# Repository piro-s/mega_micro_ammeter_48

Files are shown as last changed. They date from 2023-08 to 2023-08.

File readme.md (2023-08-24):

## Mega micro ammeter 48  
The microammeter is designed to measure small direct currents in low-voltage 
circuits and has the following characteristics:  
+ range of measured currents: 0.05 μA - 500 mA in 6 ranges;  
+ automatic range selection;  
+ results on a display 1602;  
+ building a current graph on a PC (connect via micro USB);  
+ potential at the current measurement point: 0 - 6 V;  
+ power: 5V, via connector micro USB.  
iso_v0.2_top iso_v0.2__bottom  
Устройство построено на основе статьи

---
#### Scheme:  
[Scheme_v0.2](docs/mega_micro_ammeter_48_v0.2.pdf)  

#### PCB:  
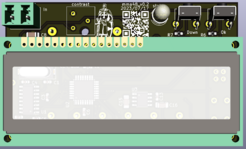
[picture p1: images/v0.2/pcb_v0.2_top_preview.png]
pcb_v0.2_top
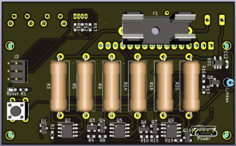
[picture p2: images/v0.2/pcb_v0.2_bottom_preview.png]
pcb_v0.2_bottom
   

---
#### Gerber:  
Archive for production:  
[gerber_v0.2](https://github.com/piro-s/mega_micro_ammeter_48/raw/main/gerber/mega_micro_ammeter_48_v0.2.zip)

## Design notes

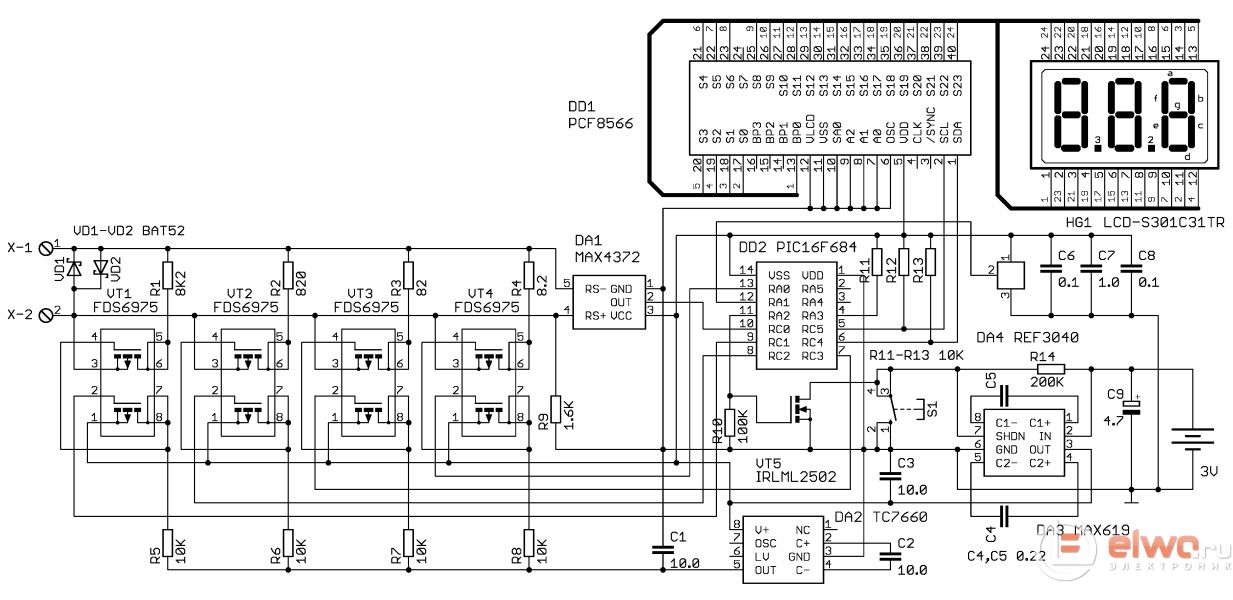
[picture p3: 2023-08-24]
docs/mikroampermetr_mk-7.jpg

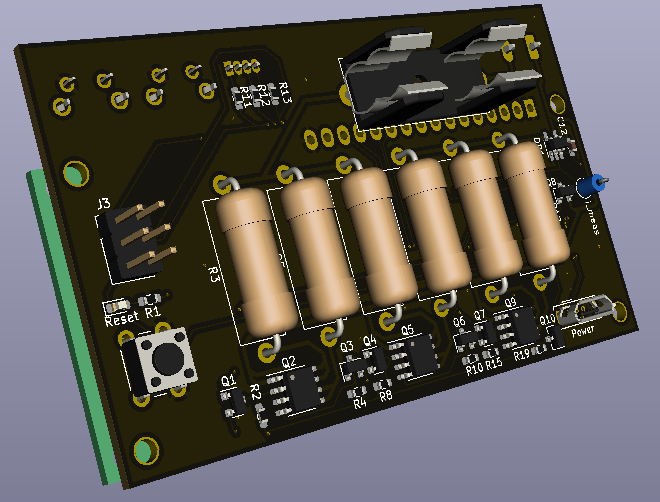
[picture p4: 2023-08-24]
images/v0.2/iso_v0.2_bottom.png

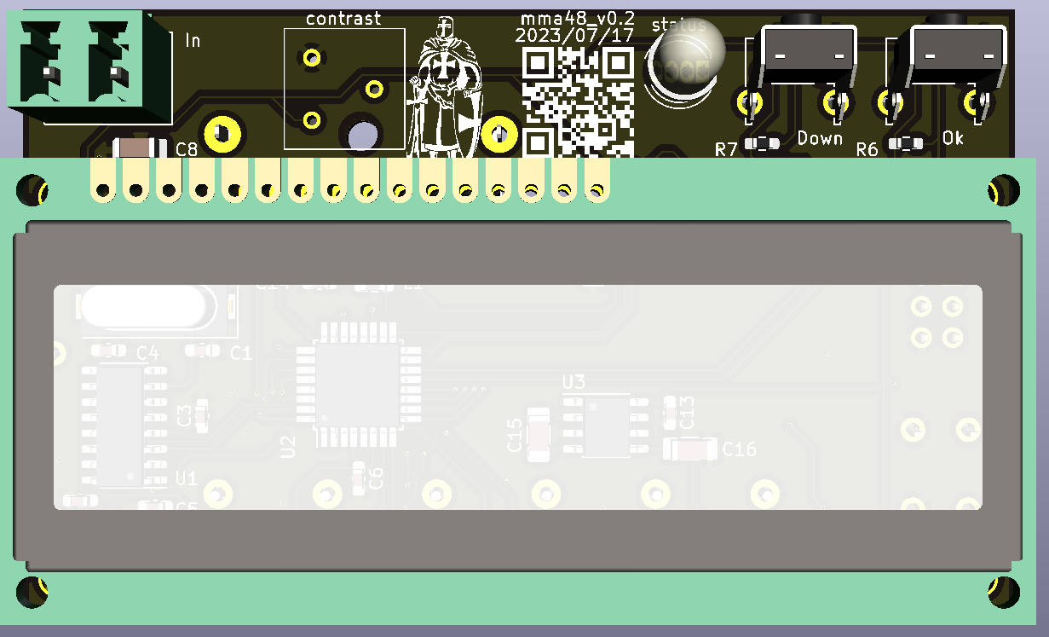
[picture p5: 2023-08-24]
images/v0.2/pcb_v0.2_top.png

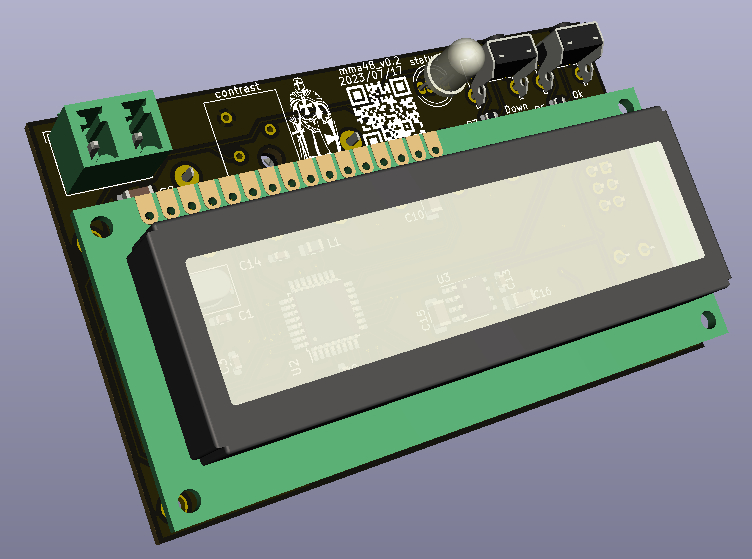
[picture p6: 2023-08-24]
images/v0.2/iso_v0.2_top.png

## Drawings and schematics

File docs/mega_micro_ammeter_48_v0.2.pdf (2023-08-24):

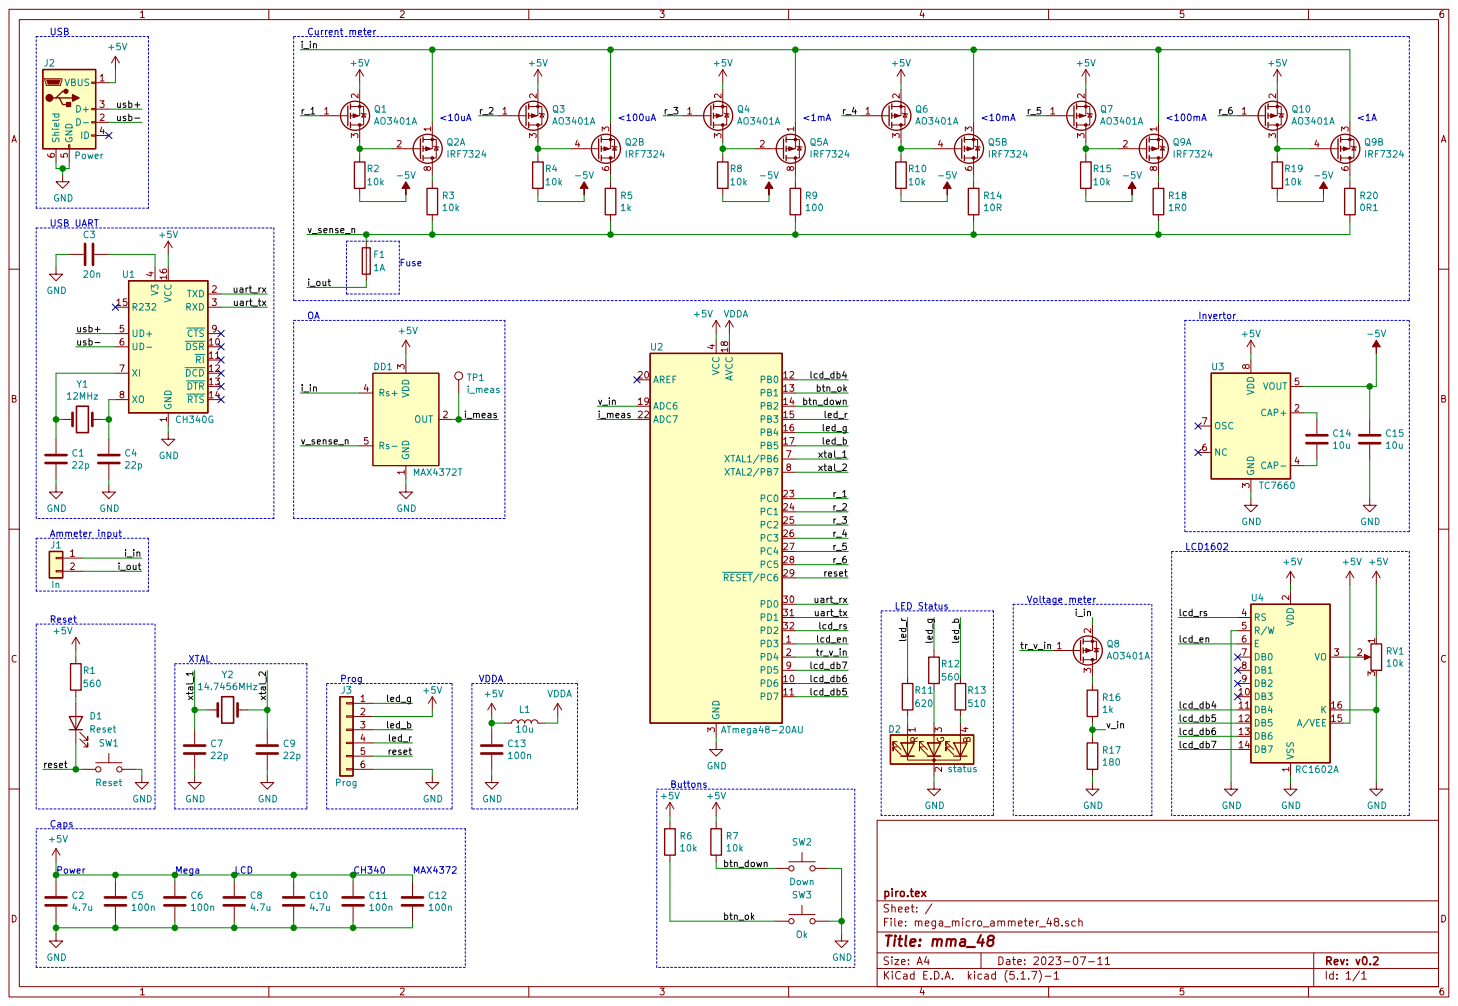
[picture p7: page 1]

1 DSR 10 RI 11 DCD 12 DTR 13 RTS 14 R232 15 VCC 16 TXD 2 RXD 3 V3

4 UD+ 5 UD- 6 XI 7 XO 8 CTS 9 U1 CH340G

3 Rs+ 4 Rs- 5 DD1 MAX4372T SW3 Ok SW2 Down R7

3 CAP- 4 VOUT 5 NC 6 OSC 7 VDD

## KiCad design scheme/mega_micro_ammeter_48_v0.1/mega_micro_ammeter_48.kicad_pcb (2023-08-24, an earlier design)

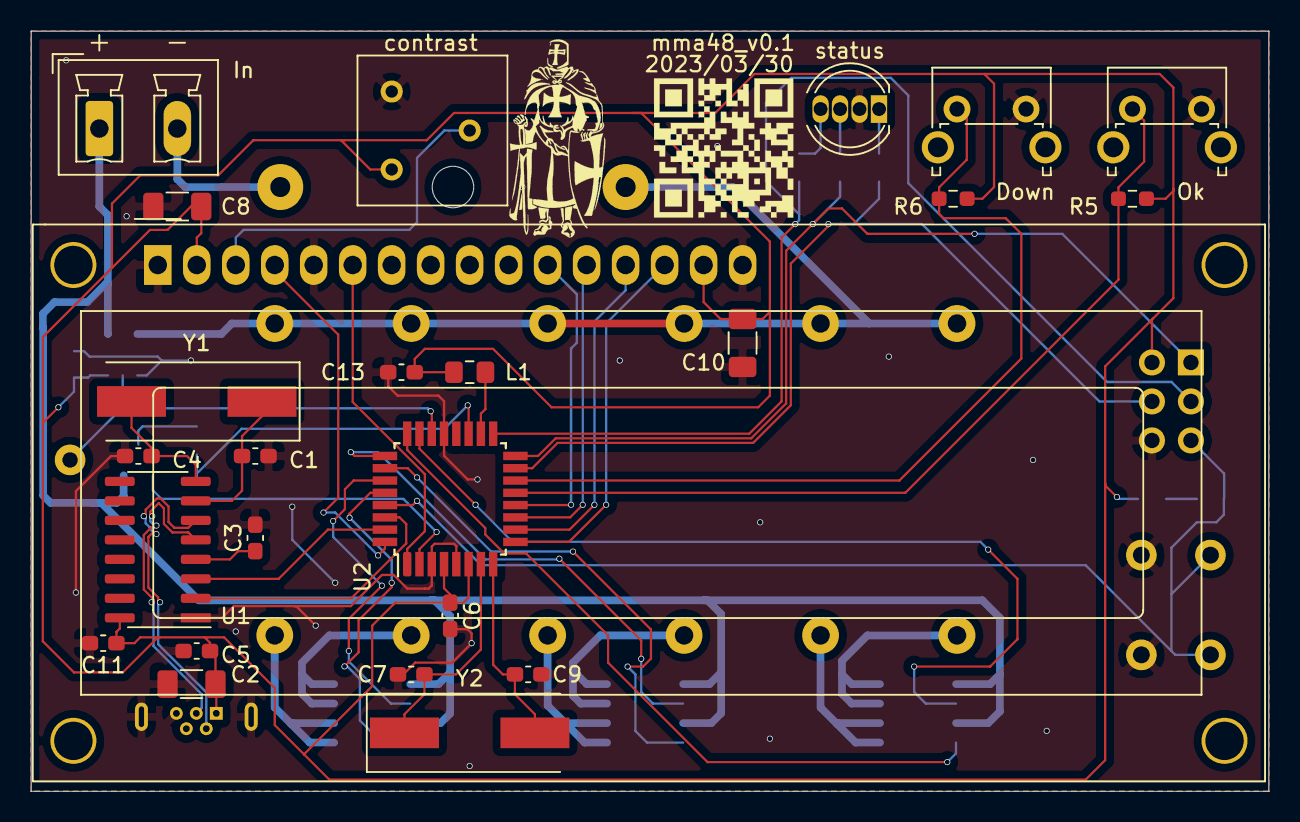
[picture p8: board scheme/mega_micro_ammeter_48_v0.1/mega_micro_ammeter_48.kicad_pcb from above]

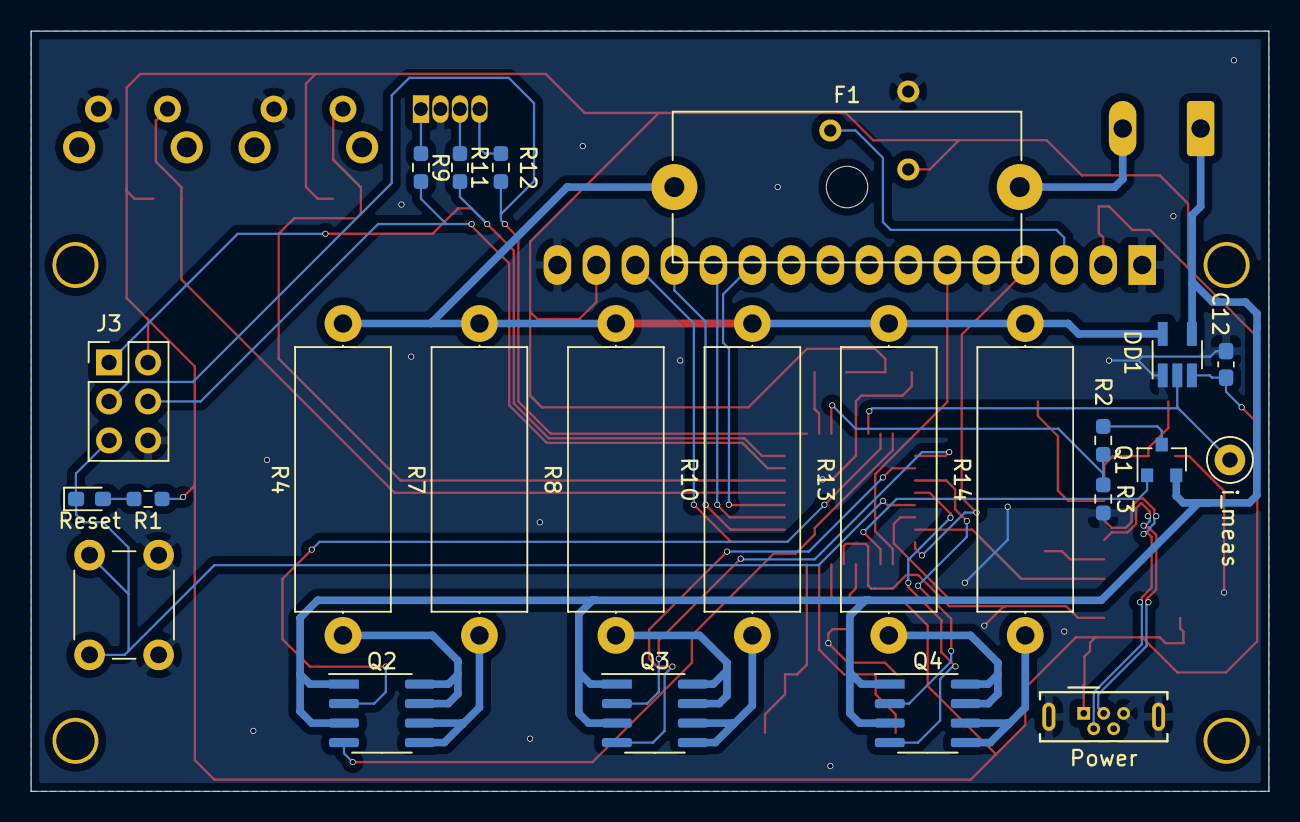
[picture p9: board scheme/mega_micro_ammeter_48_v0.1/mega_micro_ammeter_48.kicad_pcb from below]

Board: 2 copper layers, 80.6 x 49.5 mm, 49 parts (24 on the bottom side), 48 nets.

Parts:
C1, C4, C7, C9: 22p; C_0603_1608Metric_Pad1.08x0.95mm_HandSolder
C2, C8, C10: 4.7u; C_1206_3216Metric_Pad1.33x1.80mm_HandSolder
C3: 20n; C_0603_1608Metric_Pad1.08x0.95mm_HandSolder
C5, C6, C11, C12, C13: 100n; C_0603_1608Metric_Pad1.08x0.95mm_HandSolder
D1: Reset; LED_0603_1608Metric_Pad1.05x0.95mm_HandSolder
D2: status; LED_D5.0mm-4_RGB
DD1: MAX4372T; SOT-23-5_HandSoldering
F1: 1A; Fuseholder_Cylinder-5x20mm_Schurter_0031_8201_Horizontal_Op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
J1: Power; USB_Micro-B_Wuerth_614105150721_Vertical
J2: In; PhoenixContact_MCV_1,5_2-G-5.08_1x02_P5.08mm_Vertical
J3: Prog; PinHeader_2x03_P2.54mm_Vertical
L1: 10u; L_0805_2012Metric_Pad1.15x1.40mm_HandSolder
Q1: BSS83P; SOT-23
Q2, Q3, Q4: IRF7324; SOIC-8_3.9x4.9mm_P1.27mm
R1, R11: 560; R_0603_1608Metric_Pad0.98x0.95mm_HandSolder
R2: 1k; R_0603_1608Metric_Pad0.98x0.95mm_HandSolder
R3: 180; R_0603_1608Metric_Pad0.98x0.95mm_HandSolder
R4: 10k; R_Axial_DIN0617_L17.0mm_D6.0mm_P20.32mm_Horizontal
R5, R6: 10k; R_0603_1608Metric_Pad0.98x0.95mm_HandSolder
R7: 1k; R_Axial_DIN0617_L17.0mm_D6.0mm_P20.32mm_Horizontal
R8: 100; R_Axial_DIN0617_L17.0mm_D6.0mm_P20.32mm_Horizontal
R9: 620; R_0603_1608Metric_Pad0.98x0.95mm_HandSolder
R10: 10R; R_Axial_DIN0617_L17.0mm_D6.0mm_P20.32mm_Horizontal
R12: 510; R_0603_1608Metric_Pad0.98x0.95mm_HandSolder
R13: 1R0; R_Axial_DIN0617_L17.0mm_D6.0mm_P20.32mm_Horizontal
R14: 0R1; R_Axial_DIN0617_L17.0mm_D6.0mm_P20.32mm_Horizontal
RV1: 10k; Potentiometer_Bourns_3386F_Vertical
SW1: Reset; SW_PUSH_6mm
SW2: Down; SW_Tactile_SPST_Angled_PTS645Vx39-2LFS
SW3: Ok; SW_Tactile_SPST_Angled_PTS645Vx39-2LFS
TP1: i_meas; TestPoint_Loop_D1.80mm_Drill1.0mm_Beaded
U1: CH340G; SOIC-16_3.9x9.9mm_P1.27mm
U2: ATmega48-20AU; TQFP-32_7x7mm_P0.8mm
U3: RC1602A; WC1602A
Y1: 12MHz; Crystal_SMD_HC49-SD
Y2: 8MHz; Crystal_SMD_HC49-SD

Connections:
+5V: C2.1, C5.1, C6.1, C8.1, C10.1, C11.1, C12.1, C13.1, DD1.3, J1.1, J3.2, L1.1, R1.1, R5.1, R6.1, RV1.1, U1.16, U2.4, U2.6, U3.2, U3.15
/btn_down: R6.2, SW2.1, U2.14
/btn_ok: R5.2, SW3.1, U2.13
/i_in: DD1.4, J2.1, Q1.2, Q2.1, Q2.3, Q3.1, Q3.3, Q4.1, Q4.3
/i_meas: DD1.2, TP1.1, U2.22
/i_out: F1.2, J2.2
/lcd_db4: U2.12, U3.11
/lcd_db5: U2.11, U3.12
/lcd_db6: U2.10, U3.13
/lcd_db7: U2.9, U3.14
/lcd_en: U2.1, U3.6
/lcd_rs: U2.32, U3.4
/led_b: J3.3, R12.1, U2.17
/led_g: J3.1, R11.1, U2.16
/led_r: J3.4, R9.1, U2.15
/r_1: Q2.2, U2.23
/r_2: Q2.4, U2.24
/r_3: Q3.2, U2.25
/r_4: Q3.4, U2.26
/r_5: Q4.2, U2.27
/r_6: Q4.4, U2.28
/reset: D1.1, J3.5, SW1.1, U2.29
/tr_v_in: Q1.1, U2.2
/uart_rx: U1.2, U2.30
/uart_tx: U1.3, U2.31
/usb+: J1.3, U1.5
/usb-: J1.2, U1.6
/v_in: R2.2, R3.1, U2.19
/v_sense_n: DD1.5, F1.1, R4.2, R7.2, R8.2, R10.2, R13.2, R14.2
/xtal_1: C7.1, U2.7, Y2.1
/xtal_2: C9.1, U2.8, Y2.2
GND: C1.2, C2.2, C3.2, C4.2, C5.2, C6.2, C7.2, C8.2, C9.2, C10.2, C11.2, C12.2, C13.2, D2.2, DD1.1, J1.5, J1.6, J3.6, R3.2, RV1.3, SW1.2, SW2.2, SW3.2, U1.1, U2.3, U2.5, U2.21, U3.1, U3.5, U3.16
unnamed: C1.1, U1.7, Y1.1
unnamed: C3.1, U1.4
unnamed: C4.1, U1.8, Y1.2
unnamed: D1.2, R1.2
unnamed: D2.1, R9.2
unnamed: D2.3, R11.2
unnamed: D2.4, R12.2
unnamed: Q1.3, R2.1
unnamed: Q2.5, Q2.6, R7.1
unnamed: Q2.7, Q2.8, R4.1
unnamed: Q3.5, Q3.6, R10.1
unnamed: Q3.7, Q3.8, R8.1
unnamed: Q4.5, Q4.6, R14.1
unnamed: Q4.7, Q4.8, R13.1
unnamed: RV1.2, U3.3
VDDA: L1.2, U2.18

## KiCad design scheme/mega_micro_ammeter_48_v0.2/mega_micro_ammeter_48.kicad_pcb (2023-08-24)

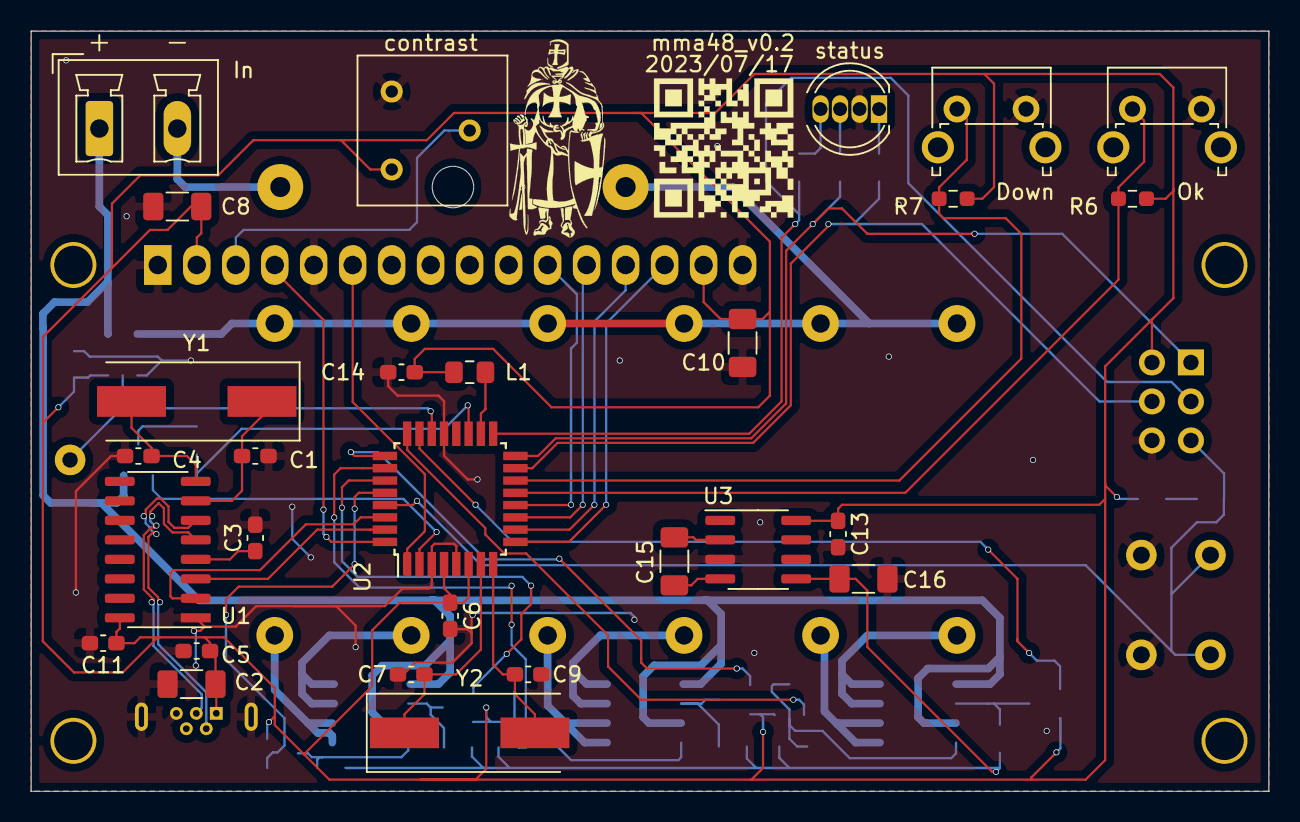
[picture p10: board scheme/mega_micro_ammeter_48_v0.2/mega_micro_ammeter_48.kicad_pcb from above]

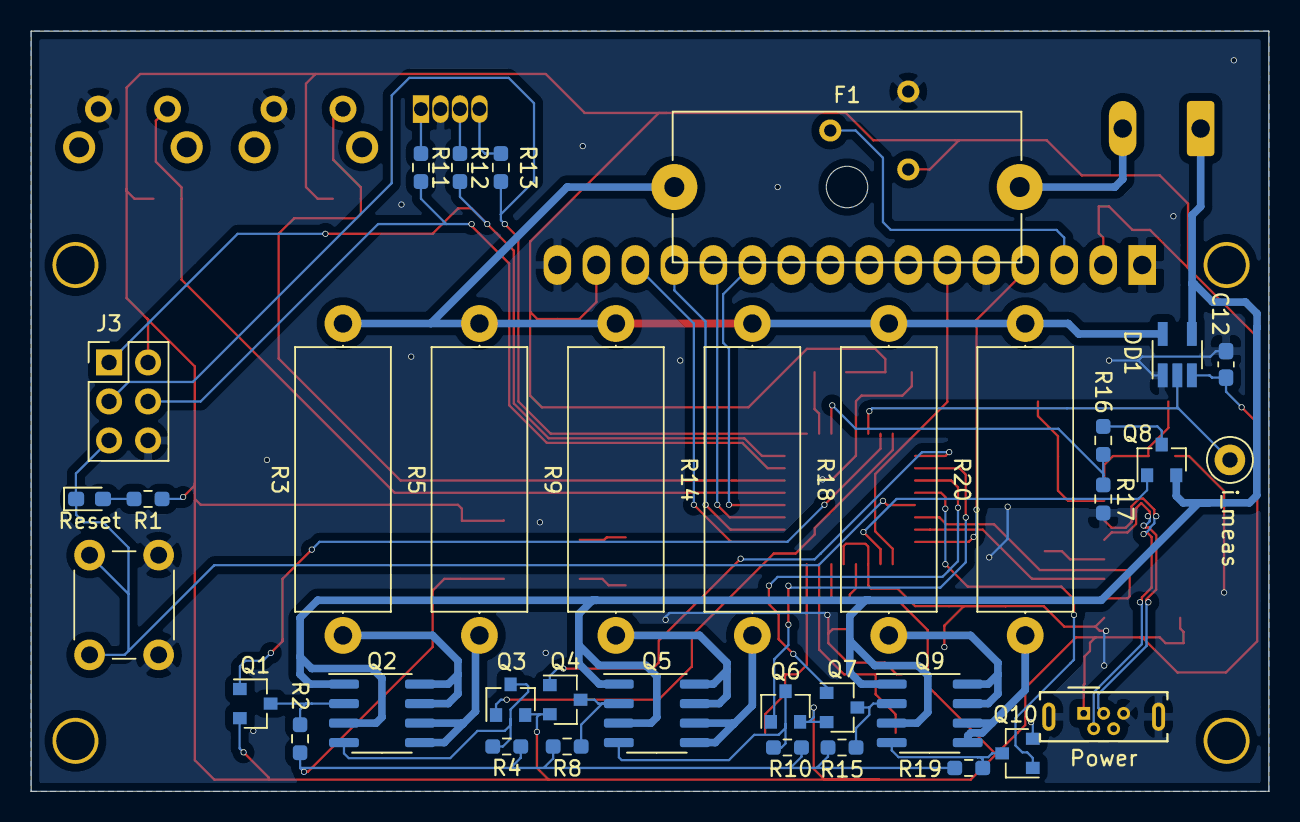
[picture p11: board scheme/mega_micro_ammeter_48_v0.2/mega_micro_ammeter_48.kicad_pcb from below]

Board: 2 copper layers, 80.6 x 49.5 mm, 65 parts (36 on the bottom side), 57 nets.

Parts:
C1, C4, C7, C9: 22p; C_0603_1608Metric_Pad1.08x0.95mm_HandSolder
C2, C8, C10: 4.7u; C_1206_3216Metric_Pad1.33x1.80mm_HandSolder
C3: 20n; C_0603_1608Metric_Pad1.08x0.95mm_HandSolder
C5, C6, C11, C12, C13, C14: 100n; C_0603_1608Metric_Pad1.08x0.95mm_HandSolder
C15, C16: 10u; C_1206_3216Metric_Pad1.33x1.80mm_HandSolder
D1: Reset; LED_0603_1608Metric_Pad1.05x0.95mm_HandSolder
D2: status; LED_D5.0mm-4_RGB
DD1: MAX4372T; SOT-23-5_HandSoldering
F1: 1A; Fuseholder_Cylinder-5x20mm_Schurter_0031_8201_Horizontal_Op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
J1: In; PhoenixContact_MCV_1,5_2-G-5.08_1x02_P5.08mm_Vertical
J2: Power; USB_Micro-B_Wuerth_614105150721_Vertical
J3: Prog; PinHeader_2x03_P2.54mm_Vertical
L1: 10u; L_0805_2012Metric_Pad1.15x1.40mm_HandSolder
Q1, Q3, Q4, Q6, Q7, Q8, Q10: AO3401A; SOT-23
Q2, Q5, Q9: IRF7324; SOIC-8_3.9x4.9mm_P1.27mm
R1, R12: 560; R_0603_1608Metric_Pad0.98x0.95mm_HandSolder
R2, R4, R6, R7, R8, R10, R15, R19: 10k; R_0603_1608Metric_Pad0.98x0.95mm_HandSolder
R3: 10k; R_Axial_DIN0617_L17.0mm_D6.0mm_P20.32mm_Horizontal
R5: 1k; R_Axial_DIN0617_L17.0mm_D6.0mm_P20.32mm_Horizontal
R9: 100; R_Axial_DIN0617_L17.0mm_D6.0mm_P20.32mm_Horizontal
R11: 620; R_0603_1608Metric_Pad0.98x0.95mm_HandSolder
R13: 510; R_0603_1608Metric_Pad0.98x0.95mm_HandSolder
R14: 10R; R_Axial_DIN0617_L17.0mm_D6.0mm_P20.32mm_Horizontal
R16: 1k; R_0603_1608Metric_Pad0.98x0.95mm_HandSolder
R17: 180; R_0603_1608Metric_Pad0.98x0.95mm_HandSolder
R18: 1R0; R_Axial_DIN0617_L17.0mm_D6.0mm_P20.32mm_Horizontal
R20: 0R1; R_Axial_DIN0617_L17.0mm_D6.0mm_P20.32mm_Horizontal
RV1: 10k; Potentiometer_Bourns_3386F_Vertical
SW1: Reset; SW_PUSH_6mm
SW2: Down; SW_Tactile_SPST_Angled_PTS645Vx39-2LFS
SW3: Ok; SW_Tactile_SPST_Angled_PTS645Vx39-2LFS
TP1: i_meas; TestPoint_Loop_D1.80mm_Drill1.0mm_Beaded
U1: CH340G; SOIC-16_3.9x9.9mm_P1.27mm
U2: ATmega48-20AU; TQFP-32_7x7mm_P0.8mm
U3: TC7660; SOIC-8_3.9x4.9mm_P1.27mm
U4: RC1602A; display_1602_nofootprint
Y1: 12MHz; Crystal_SMD_HC49-SD
Y2: 14.7456MHz; Crystal_SMD_HC49-SD

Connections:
+5V: C2.1, C5.1, C6.1, C8.1, C10.1, C11.1, C12.1, C13.1, C14.1, DD1.3, J2.1, J3.2, L1.1, Q1.2, Q3.2, Q4.2, Q6.2, Q7.2, Q10.2, R1.1, R6.1, R7.1, RV1.1, U1.16, U2.4, U2.6, U3.8, U4.2, U4.15
-5V: C16.1, R2.2, R4.2, R8.2, R10.2, R15.2, R19.2, U3.5
/btn_down: R7.2, SW2.1, U2.14
/btn_ok: R6.2, SW3.1, U2.13
/i_in: DD1.4, J1.1, Q2.1, Q2.3, Q5.1, Q5.3, Q8.2, Q9.1, Q9.3
/i_meas: DD1.2, TP1.1, U2.22
/i_out: F1.2, J1.2
/lcd_db4: U2.12, U4.11
/lcd_db5: U2.11, U4.12
/lcd_db6: U2.10, U4.13
/lcd_db7: U2.9, U4.14
/lcd_en: U2.1, U4.6
/lcd_rs: U2.32, U4.4
/led_b: J3.3, R13.1, U2.17
/led_g: J3.1, R12.1, U2.16
/led_r: J3.4, R11.1, U2.15
/r_1: Q1.1, U2.23
/r_2: Q3.1, U2.24
/r_3: Q4.1, U2.25
/r_4: Q6.1, U2.26
/r_5: Q7.1, U2.27
/r_6: Q10.1, U2.28
/reset: D1.1, J3.5, SW1.1, U2.29
/tr_v_in: Q8.1, U2.2
/uart_rx: U1.2, U2.30
/uart_tx: U1.3, U2.31
/usb+: J2.3, U1.5
/usb-: J2.2, U1.6
/v_in: R16.2, R17.1, U2.19
/v_sense_n: DD1.5, F1.1, R3.2, R5.2, R9.2, R14.2, R18.2, R20.2
/xtal_1: C7.1, U2.7, Y2.1
/xtal_2: C9.1, U2.8, Y2.2
GND: C1.2, C2.2, C3.2, C4.2, C5.2, C6.2, C7.2, C8.2, C9.2, C10.2, C11.2, C12.2, C13.2, C14.2, C16.2, D2.2, DD1.1, J2.5, J2.6, J3.6, R17.2, RV1.3, SW1.2, SW2.2, SW3.2, U1.1, U2.3, U2.5, U2.21, U3.3, U4.1, U4.5, U4.16
unnamed: C1.1, U1.7, Y1.1
unnamed: C3.1, U1.4
unnamed: C4.1, U1.8, Y1.2
unnamed: C15.1, U3.2
unnamed: C15.2, U3.4
unnamed: D1.2, R1.2
unnamed: D2.1, R11.2
unnamed: D2.3, R12.2
unnamed: D2.4, R13.2
unnamed: Q1.3, Q2.2, R2.1
unnamed: Q2.4, Q3.3, R4.1
unnamed: Q2.5, Q2.6, R5.1
unnamed: Q2.7, Q2.8, R3.1
unnamed: Q4.3, Q5.2, R8.1
unnamed: Q5.4, Q6.3, R10.1
unnamed: Q5.5, Q5.6, R14.1
unnamed: Q5.7, Q5.8, R9.1
unnamed: Q7.3, Q9.2, R15.1
unnamed: Q8.3, R16.1
unnamed: Q9.5, Q9.6, R20.1
unnamed: Q9.7, Q9.8, R18.1
unnamed: Q9.4, Q10.3, R19.1
unnamed: RV1.2, U4.3
VDDA: L1.2, U2.18

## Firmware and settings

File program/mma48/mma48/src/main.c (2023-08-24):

/*
 * mma48.c
 *
 * Created: 12.04.2023 10:06:14
 * Author : piro.tex
 */ 

///--- includes
#include <avr/io.h>
#include <avr/interrupt.h>
#include "../inc/main.h"
#include "../inc/lcd_1602.h"
#include "../inc/buttons.h"


///--- defines
#define relay_port_set DDRC
#define relay_port PORTC

#define voltage_port_set DDRD
#define voltage_port PORTD
#define voltage_pin 4


///--- enums
enum enums
{
    //-- Channels ADC
    ch_voltage                  = 6, // ADC channel 6
    ch_current                  = 7, // ADC channel 7
        
    //-- Relay pins
    relay_1                     = 0, // Relay 1
    relay_2                     = 1, // Relay 2
    relay_3                     = 2, // Relay 3
    relay_4                     = 3, // Relay 4
    relay_5                     = 4, // Relay 5
    relay_6                     = 5, // Relay 6
    
    //-- Shunt resistance
    shunt_1                     = 10000, // 10k Ohm
    shunt_2                     = 1000, // 1k Ohm
    shunt_3                     = 100, // 100 Ohm
    shunt_4                     = 10, // 10 Ohm
    shunt_5                     = 1, // 1 Ohm
    shunt_6                     = 10, // 0.1 Ohm !!!
    
    //-- Errors
    error_no                    = 0xE0, // No error
    error_max_cur               = 0xE1, // Error - max current
    error_max_vol               = 0xE2, // Error - max voltage (10V and higher)
    
    //-- Flag states
    flag_off                    = 0, // Flag reset
    flag_on                     = 1, // Flag set
};


///--- structs
typedef struct
{
    uint8_t ch; // Channel
    uint8_t flag; // Flag irq complete
    uint8_t flag_ch; // Flag channel change
    
    // Results
    uint8_t adc_l; // ADC data low byte (ADCL)
    uint8_t adc_h; // ADC data high byte (ADCH)
    uint16_t result; // Result
} adc_str; // Struct for adc

typedef struct  
{
    uint8_t relay; // Current open relay
    uint8_t error; // Error
    
} device_str;


///--- adc
void adc_init(void);
void adc_start(void); // Start ADC conversion
void adc_read(void); // Read data from ADC (data in adc->result)
ISR(ADC_vect); // Interrupt hundler


///--- relay
void relay_init(void); // Init relay pins
void relay_close_all(void); // Close all relays
void relay_switch(uint8_t relay); // Switch to specified relay
void relay_next(void); // Switch to next relay
void relay_prev(void); // Switch to prev relay


///--- tim
void tim_init(void); // Init TIM
ISR(TIMER0_COMPA_vect); // IRQ handler


///--- uart
void uart_init(void); // Init UART
ISR(USART_RX_vect); // IRQ handler


///--- functions
void voltage_init(void); // Init voltage transistor pin


///--- Variables
adc_str adc =
{
    .flag = flag_off, // Flag irq complete
    .flag_ch = flag_off, // Flag channel change
    
    // Results
    .adc_l = 0, // ADC data low byte (ADCL)
    .adc_h = 0, // ADC data high byte (ADCH)
    .result = 0 // Result
};

device_str device = 
{
    .relay = relay_1, // Current relay
    .error = error_no // Error
};

uint8_t receive = 0;

int main(void)
{   
    lcd_init(); // Init LCD 
    adc_init(); // Init ADC
    relay_init(); // Init relays
    voltage_init(); // Init voltage transistor pin
    tim_init(); // Init TIM
    uart_init(); // Init UART
    
    
    DDRB &= ~(1 << 1);
    
    //ClearBit(relay_port, relay_4);
    //relay_next();
    //relay_next();
    //relay_next();
    //relay_switch(relay_4);
    //lcd_set_cursor(0, 0);
    //lcd_print_string("Button: ");
    lcd_clear();    
    lcd_set_cursor(0, 0);
    lcd_print_string("ADC: ");
    
    lcd_set_cursor(1, 0);
    lcd_print_string("I: ");
    
    lcd_set_cursor(1, 9);
    lcd_print_string("V: ");
    
    //adc_start();
    
    SetPinOutput(DDRB, 3);
    ClearBit(PORTB, 3);
    
    
    char vivod[16] = {0};
    char vivod_adc[3] = {0};
    char vivod_vol[3] = {0};
    char vivod_cur[3] = {0};
    
    ////float vol_multi = 5.f * 1150.f / 1024.f / 150.f; // Voltage multiplier
    //float vol_multi = 0.0374f; // Voltage multiplier
    //float vol_multi = 5.f * (996.f + 149.9) / 149.9 / 1024.f; // Voltage multiplier
    float vol_multi = 0.03733f; // Voltage multiplier
    
    //float cur_multi = 5.f / 1024.f / 20.f / shunt; // Current multiplier
    //float cur_multi_1 = 24.41406f; // Current multiplier - relay 1 (nA)
    //float cur_multi_2 = 244.1406f; // Current multiplier - relay 2 (nA)
    //float cur_multi_3 = 2.441406f; // Current multiplier - relay 3 (uA)
    //float cur_multi_4 = 24.41406f; // Current multiplier - relay 4 (uA)
    //float cur_multi_5 = 244.1406f; // Current multiplier - relay 5 (uA)
    //float cur_multi_6 = 2.441406f; // Current multiplier - relay 6 (mA)
    float cur_multi_1 = 0.00002441406f; // Current multiplier - relay 1 (mA)
    float cur_multi_2 = 0.0002441406f; // Current multiplier - relay 2 (mA)
    float cur_multi_3 = 0.002441406f; // Current multiplier - relay 3 (mA)
    float cur_multi_4 = 0.02441406f; // Current multiplier - relay 4 (mA)
    float cur_multi_5 = 0.2441406f; // Current multiplier - relay 5 (mA)
    float cur_multi_6 = 2.441406f; // Current multiplier - relay 6 (mA)
        
    float voltage = 0;
    float current = 0;
    
    
    SetBit(voltage_port, voltage_pin); // Voltage off
    
    uint8_t times = 0;
    lcd_set_cursor(0, 10);
    lcd_print_symbol(0x78);
    
    while (1) 
    {
        lcd_set_cursor(0, 11);
        lcd_print_symbol(receive);
        //lcd_set_cursor(0, 8);
        //if(button_read(button_ok))
            //lcd_print_symb('1');
        //else
            //lcd_print_symb('0');
        
        //while(!(UCSR0A & (1 << UDRE0))); // Waiting data register is empty
        //UDR0 = 0x78; // Send byte
        //while (!(UCSR0A & (1 << TXC0))); // Waiting transmit is over
        //UDR0 = 0x78;
        //while (!(UCSR0A & (1 << TXC0))); // Wait transmit complete
        //UCSR0A |= (1 << TXC0); // Clear flag transmit complete
        //UCSR0B |= (1 << UDRIE0); // Разрешение прерывания по опустошению буфера UDR
        //_delay_ms(200);
        
        if(button_read(button_ok))
        {
            device.error = error_no;
            relay_switch(relay_1);
        }            
            
        adc_read();
        lcd_set_cursor(0, 14);
        lcd_print_symbol('R');
        lcd_print_symbol(0x31 + device.relay);
        if(adc.result > 800)
        {
            if(device.relay != relay_6)
            {
                relay_next();
            }               
            else
            {
                if(device.error != error_no)
                {
                    //vivod_adc[0] = 'M';
                    //vivod_adc[1] = 'a';
                    //vivod_adc[2] = 'x';
                    //strcpy(vivod_adc, "Max");
                    //vivod_adc = "Max";
                    lcd_set_cursor(0, 5);
                    lcd_print_string("Max");
                    relay_close_all();
                    device.error = error_max_cur;
                }
            }
        }
        else
        {
            if(!(ADMUX & (1 << MUX0)))
                voltage = adc.result * vol_multi;
            else
            {
                if(device.relay == relay_1)
                    current = adc.result * cur_multi_1;
                else if(device.relay == relay_2)
                    current = adc.result * cur_multi_2;
                else if(device.relay == relay_3)
                    current = adc.result * cur_multi_3;
                else if(device.relay == relay_4)
                    current = adc.result * cur_multi_4;
                else if(device.relay == relay_5)
                    current = adc.result * cur_multi_5;
                else if(device.relay == relay_6)
                    current = adc.result * cur_multi_6;
            }                
        
            times++;
            if(times < 1)
            {
                if(ADMUX & (1 << MUX0))
                    adc.flag_ch = flag_on;
            }
            else if(times < 11)
            {
                if(!(ADMUX & (1 << MUX0)))
                    adc.flag_ch = flag_on;
            }
            else
            {
                times = 0;
                lcd_clear_area(0, 5, 4); // Clear ADC value
                lcd_clear_area(1, 3, 5); // Clear current
                lcd_clear_area(1, 12, 4); // Clear voltage
            }
        
        
            lcd_set_cursor(0, 5);
            lcd_print_uint(adc.result);
        
            lcd_set_cursor(1, 3);
            lcd_print_float(current);
            lcd_print_string(vivod_cur);
        
            lcd_set_cursor(1, 12);
            lcd_print_float(voltage);
            lcd_print_string(vivod_vol);
        }

        _delay_ms(20);
    }
}


///--------------------------------------------------------------------------///
///--- adc
void adc_init(void) // Init ADC
{
    //-- Reset state ADC
    ADMUX = 0x00; // Reset register ADMUX
    ADCSRA = 0x00; // Reset register ADCSRA
    ADCSRB = 0x00; // Reset register ADCSRB
    DIDR0 = 0x00; // Reset register DIDR0
    
    
    //-- Voltage reference
    ADMUX |= (1 << REFS0); // AVcc
    
    //-- Result adjust
    ADMUX &= ~(1 << ADLAR); // Right adjust result
    
    //-- Channels
    ADMUX |= ((1 << MUX2) | (1 << MUX1)); // Channel 6
    
    //-- Prescaler
    ADCSRA |= ((1 << ADPS2) | (1 << ADPS1) | (1 << ADPS0)); // Prescaler 128
    
    //-- Auto trigger
    ADCSRA |= (1 << ADATE); // Auto trigger enable
    ADCSRB &= ~((1 << ADTS2) | (1 << ADTS1) | (1 << ADTS0)); // Free run
    
    //-- Interrupt
    ADCSRA |= (1 << ADIE); // ADC interrupt enable
    sei(); // Global interrupts enable
    
    ADCSRA |= (1 << ADEN); // ADC enable
    
    return;
} // void adc_init(void)

void adc_start(void) // Start ADC conversion
{
    ADCSRA |= (1 << ADSC); // Start conversion
    
    return;
} // void adc_start(void)

void adc_read(void) // Read data from ADC (data in adc.result)
{
    if(adc.flag == flag_on) // If flag set
    {
        uint16_t result = 0;
        result = (adc.adc_h << 8) | adc.adc_l;
        
        adc.flag = flag_off;
        adc.result = result;
    }
    
    return;
} // void adc_read(void)


ISR(ADC_vect) // Interrupt hundler
{
    adc.flag = flag_on;
    adc.adc_l = ADCL;
    adc.adc_h = ADCH;
    
    //InvBit(ADMUX, MUX0);
    
    if(adc.flag_ch == flag_on)
    {
        if(!(ADMUX & (1 << MUX0)))
            ADMUX |= (1 << MUX0);
        else
            ADMUX &= ~(1 << MUX0);
        
        adc.flag_ch = flag_off;
    }
    
    return;
} // ISR(ADC_vect)


///--------------------------------------------------------------------------///
///--- relay
void relay_init(void) // Init relay pins
{ 
    SetPinOutput(relay_port_set, relay_1); // 10k
    SetBit(relay_port, relay_1);
    
    SetPinOutput(relay_port_set, relay_2); // 1k
    SetBit(relay_port, relay_2);
    
    SetPinOutput(relay_port_set, relay_3); // 100
    SetBit(relay_port, relay_3);
    
    SetPinOutput(relay_port_set, relay_4); // 10
    SetBit(relay_port, relay_4);
    
    SetPinOutput(relay_port_set, relay_5); // 1
    SetBit(relay_port, relay_5);
    
    SetPinOutput(relay_port_set, relay_6); // 0.1
    SetBit(relay_port, relay_6);
} // void relay_init(void)

void relay_close_all(void) // Close all relays
{
    SetBit(relay_port, relay_1);
    SetBit(relay_port, relay_2);
    SetBit(relay_port, relay_3);
    SetBit(relay_port, relay_4);
    SetBit(relay_port, relay_5);
    SetBit(relay_port, relay_6);
    
    return;
} // void relay_close_all(void)
    
void relay_switch(uint8_t relay) // Switch to specified relay
{
    SetBit(relay_port, device.relay);
    ClearBit(relay_port, relay);
    device.relay = relay;
    
    return;
} // void relay_switch(uint8_t relay)

void relay_next(void) // Switch to next relay
{
    //-- Close after last relay
    if(device.relay == relay_6)
        SetBit(relay_port, relay_6);
    else
    {
        SetBit(relay_port, device.relay++);
        ClearBit(relay_port, device.relay);
    }
    
    return;
} // void relay_next(void)

void relay_prev(void) // Switch to prev relay
{
    //-- Close after first relay
} // void relay_prev(void)


///--------------------------------------------------------------------------///
///--- tim
void tim_init(void) // Init TIM
{
    TCCR0A |= (1 << WGM01); // Timer mode - CTC
    TIMSK0 |= (1 << OCIE0A); // Output Compare Match A Interrupt Enable
    OCR0A = 0x39; // Counter up to 1ms
    OCR0B = 0x99;
    
    return;
} // void tim_init(void)

ISR(TIMER0_COMPA_vect) // IRQ handler
{
    
    
    return;
} // ISR(TIMER0_COMPA_vect)


///--------------------------------------------------------------------------///
///--- uart
void uart_init(void) // Init UART
{
    //-- Init uart to pc
    // 8 data, no parity, 1 stop bit, baud rate 115200
    uint32_t baudrate = 115200;
    
    UBRR0H = (unsigned char)((F_CPU / 16 / baudrate - 1) >> 8); // Set baudrate
    UBRR0L = (unsigned char)(F_CPU / 16 / baudrate - 1); // Set baudrate
    UCSR0B |= (1 << RXCIE0); // Interrupt to RX
    UCSR0B |= (1 << RXEN0) | (1 << TXEN0); // Start transmitter and receiver
    
    sei(); // Global interrupts enable
    
    return;
} // void uart_init(void)

ISR(USART_RX_vect) // IRQ handler
{
    //lcd_set_cursor(0, 11);
    //lcd_print_symbol(UDR0); // Print receive symbol
    SetBit(PORTB, 3);
    //uint8_t byute = UDR0;
    //UDR0 = byute;
    //while (!(UCSR0A & (1 << TXC0))); // Wait transmit complete
    //UCSR0A |= (1 << TXC0); // Clear flag transmit complete
    receive = UDR0;
    while(!(UCSR0A & (1 << UDRE0))); // Waiting data register is empty
    UDR0 = receive;
    UCSR0A &= ~(1 << RXC0); // Clear flag receive complete
	
    return;
} // ISR(USART_RX_vect)


///--------------------------------------------------------------------------///
///--- functions
void voltage_init(void) // Init voltage transistor pin
{
    SetPinOutput(voltage_port_set, voltage_pin);
    ClearBit(voltage_port, voltage_pin);
    
    return;
} // void voltage_init(void)

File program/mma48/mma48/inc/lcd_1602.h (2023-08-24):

/*
 * lcd_1602.h
 *
 * Library for LCD 1602.
 * 
 * Library information:
 * - 4 bit data (change pins in defines if needed).
 * - font 5x8;
 * - no display shift. 
 *
 * Created: 12.04.2023 10:40:12
 *  Author: piro.tex
 */ 

#ifndef __lcd_1602_h__
#define __lcd_1602_h__

///--- includes
#include <avr/io.h>
#include "main.h"


///--- defines
#define lcd_rs_port_set DDRD
#define lcd_rs_port PORTD
#define lcd_rs_pin 2

#define lcd_e_port_set DDRD
#define lcd_e_port PORTD
#define lcd_e_pin 3

#define lcd_db4_port_set DDRB
#define lcd_db4_port PORTB
#define lcd_db4_pin 0
#define lcd_db5_port_set DDRD
#define lcd_db5_port PORTD
#define lcd_db5_pin 7
#define lcd_db6_port_set DDRD
#define lcd_db6_port PORTD
#define lcd_db6_pin 6
#define lcd_db7_port_set DDRD
#define lcd_db7_port PORTD
#define lcd_db7_pin 5


///--- enums
enum lcd
{
    lcd_rs_c        = PinReset, // LCD command
    lcd_rs_d        = PinSet, // LCD data
    
    lcd_row         = 2, // LCD row
    lcd_column      = 16, // LCD column
};


///--- functions
void lcd_write_4bit(uint8_t data); // Send data (4 bits)
void lcd_write(uint8_t rs, uint8_t data); // Send data or command
void lcd_init(void); // Init LCD

void lcd_set_cursor(uint8_t r, uint8_t c); // Set cursor
void lcd_print_symbol(char symbol); // Print symbol
void lcd_print_string(char* string); // Print string
void lcd_print_uint(uint32_t value); // Print uint16_t
void lcd_print_float(float value); // Print float
void lcd_clear(void); // Clear LCD output
void lcd_clear_area(uint8_t r, uint8_t c, uint8_t length); // Clear LCD area


#endif // __lcd_1602_h__
